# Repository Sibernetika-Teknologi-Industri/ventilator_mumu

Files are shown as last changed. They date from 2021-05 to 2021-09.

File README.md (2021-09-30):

# venti
Low Cost Ventilator - ITB

## Phase 1:
- Kode stepper awal + Kalibrasi
- Kode nextion awal

## Phase 2:
- Kode Integrasi
- Sampai test awal @ salman (8 April 2020)

## Phase 3:
- Pengembangan SIMV

## Phase 4:
- Pengembangan SIMV Lanjutan

## Phase 6:
- Backup setelah uji pre-klinis
- Persiapan pengembangan lanjutan per 25 Mei 2021

## Phase 8:
- IR Calculation from sensor
- Fighting and Spurious Alarm
- Mandatory Pressure Control

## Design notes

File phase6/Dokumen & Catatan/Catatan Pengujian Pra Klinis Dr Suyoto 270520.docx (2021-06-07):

# Catatan Pengujian Pre-klinis Ventilator MUMU

Tanggal: 16 November 2020

Tempat: RS Dr. Suyoto, Jakarta Selatan

Narasumber: Dr.

Notulen: Prasetyo W. (prasetyowls12 at yah00 dot c0m)

Catatan dari Dokter :

1. Tombol EMGS dapat dihapuskan saja (No issues)
2. Alatnya sepertinya lebih baik dijadikan transport (2-3 jam, bisa dicolok ke ambulan, tapi bentuk perlu lebih compact), kalau untuk ICU belum bisa (Diskusi lanjutan di internal→P Augie)
3. Volume kalau bisa hingga 100 cc (untuk anak) (trial & error)-→Harus ada fluke ,diperlukan diskusi di internal→P Augie…(Mempertimbangkan standar yg dipilih antara BPFK dan Masukan Dokter Suyoto)
4. Sensor sirkuit tube udara sebaiknya diletakkan di awal dan di dalam mesin, sehingga tidak keluar banyak selang. -→Isu harus cari komponen Connector Selang (dulu material sulit didapat)
5. Perlu tambahan Indikator RR dan IE aktual pasien (trial & error)
6. Perlu tambahan indicator trigger napas dari pasien. Dari mode mandatory ke assisted tidak perlu dibuat beralih secara otomatis, tetapi ditampilkan indicator trigger saja untuk informasi ke perawat. (trial & error)
7. Perlu ditambahkan mode pressure: mandatory dan assisted (trial & error)---diperlukan narasumber (dokter)-→ utk kepastian agar tidak melakukan kerja ulang.

Punchlist:

1. Perbaikan volume assisted???
2. Perbaikan Fighting / Trigger detection???
3. Perbaikan sensor dan sirkuit udara
4. Penambahan Mode Pressure mandatory dan assited???
5. Penambahan sensor dan indikator aktual IE dan RR
6. Penambahan Volume kalau bisa hingga 100 cc (untuk anak)???
7. Kehandalan sensor volume
8. Koreksi metode instalasi sensor oksigen.
9. Humidifier ?????

Based On Proposal :

1. Detail design Full Scale Sistem Ventilator dengan Sistem Analisis untuk memenuhi Standar ISO 80601-2-12
- Drawing design
2. Satu (1) unit Prototipe Sistem Ventilator dengan Sistem Analisis untuk memenuhi Standar ISO 80601-2-12 yang terdiri dari:
- Analyzer
- ~~Flow Sensor~~
- ~~Humidifier~~
- ~~CO2 Sensor~~
- ~~Exhalation Valve~~
- Gas Mixture System
- ~~Servo Valve~~ ~~(Problem di Oli) –~~ ~~Untuk~~ ~~mixture O2~~
3. Fitur Sistem Ventilator dengan Sistem Analisis untuk memenuhi Standar ISO 80601-2-12
- ~~Volume & rate--~~~~→~~~~Diupdate~~ ~~& explore~~
- ~~Lung Compliance~~
- Safety--→Diupdate & explore
- SIMV (Synchronized Intermittent Mandatory Ventilation)
- ~~O2 Control~~
- ~~PEEP (Positive-end expiratory pressure) Control~~
- ~~Pressure Support~~
- ~~CPAP (Continuous Positive Airways~~ ~~Pressur~~

Kesimpulan :

1. Harus buat produk ventilator dng tambahan fitur
2. Perlu diskusi terkait kepastian desain keseluruhan (default atw explore-→ desain mobile)

Estimasi kalau desain default→3-4 bulan

3. BUat rancangan BOM, Timeline dan Action Plan.

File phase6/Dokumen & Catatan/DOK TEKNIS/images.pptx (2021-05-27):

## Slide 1

Kecepatan
Motor

% Slope Factor
(akselerasi & deselerasi)

Time Exhale

Waktu

Time Inhale

Time Breath

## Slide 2

Tegangan

1 pulse/
1 step

Delay Inhale

Waktu

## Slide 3

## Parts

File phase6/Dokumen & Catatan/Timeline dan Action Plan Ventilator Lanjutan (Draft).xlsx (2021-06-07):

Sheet: Material Order (BoM)
Estimasi BOQ Ventilator (include Fluke)
No | Item | Spesifikasi | Jumlah | Unit | Harga | Total | Referensi
PENGEMBANGAN SISTEM GERAK DAN MOTOR (SISTEM MEKANIK VENTILATOR) |  |  |  |  |  | Rp 50000000.00
1 | Sistem Mekanik & Customize | - Linear Guide - Linear Block - Timing Pulley - Timing Belt - Lengan Penekan - Base - Baki - Motor Holder - Bolt Screw - Nut - Baut,Mur,dll | 1 | set | Rp 25000000.00 | Rp 25000000.00 | Estimasi Biaya Mekanik
2 | Motor Servo | Delta Servo 1,5 kW | 1 | set | Rp 25000000.00 | Rp 25000000.00 | PT Delta
PENGEMBANGAN BREATHING SYSTEM |  |  |  |  |  | Rp 7135000.00
1 | Flow Sensor Hamilton (Tubing) | Support Mesin Ventilator : Type : Adult/Pediatric Galileo/Raphael/C1/T1/MR1/C2/C3 | 1 | pcs | Rp 750000.00 | Rp 750000.00 | https://tokopedia.link/m18e7W5Vjbb
2 | PEEP Valve | PEEP(Positif End Expiratory Pressure) VALVE | 1 | pcs | Rp 1400000.00 | Rp 1400000.00 | https://tokopedia.link/A1IRCEcWjbb
3 | Reusable Resuscitator (Ambu Bag & Accesorries) | - Resuscitator silicon bag x 1pc - Reservoir bag x 1pcs - 02 tubing x 1 pcs '- Mask x 1 pcs - Airway x 3 size 1 pcs each - 1 carry case | 1 | pcs | Rp 750000.00 | Rp 750000.00 | https://tokopedia.link/8MXMOnuWjbb
4 | Breathing Circuit | Breathing Circuit Ventilator Kelengkapan -Circuit -Chamber -Water Trap -Heater wire -Connector | 1 | set | Rp 550000.00 | Rp 550000.00 | https://tokopedia.link/PSInVTSYjbb
5 | Oxygen supply (Tabung) | - Cylinder Tank Ocygen - Furemed Oxygen Regulator - F roda Oxygen CAT - Hospitech Oxygen tubing conn | 1 | set | Rp 1185000.00 | Rp 1185000.00 | Sakura | Perlu ditambahkan aksesoris: 3D printing, dsb
6 | Accessories (3 D Printing, Selang Tambahan) |  | 1 | lot | Rp 2500000.00 | Rp 2500000.00
PENGEMBANGAN SUPPORT DAN CASING |  |  |  |  |  | Rp 7200000.00
1 | Casing | Bahan akrilik | 1 | unit | Rp 1700000.00 | Rp 1700000.00 | PO Cipta Jaya Acrilic
2 | Meja Lemari | Bahan Stainless | 1 | unit | Rp 4500000.00 | Rp 4500000.00 | PO Biru Karya pratama
3 | Accessories (Peredam Suara & Getaran) | Busa , bahan peredam lainnya | 1 | lot | Rp 1000000.00 | Rp 1000000.00
PENGEMBANGAN RANGKAIAN ELEKTRONIK (SISTEM KONTROL VENTILATOR) |  |  |  |  |  | Rp 213923900.00
1 | XL4015 DC-DC Step Down | Variant : Standard | Extra Adjustable Current | Extra Voltmeter Input Voltage : 4 ~ 38 V Adjustable Output Voltage : 1.25 ~ 36 V Output Current : 5A Efficiency : max. 96% Operating Frequency : 180 kHz Operating Temperature : -40° ~ 85° C | 1 | pcs | Rp 25900.00 | Rp 25900.00 | https://tokopedia.link/8o8zMv7Ujbb
2 | Limit Switch CM-1703 | CM Micro Switch Type : CM-1703 Merk : Fort | 2 | pcs | Rp 25000.00 | Rp 50000.00 | https://tokopedia.link/tyngZXiVjbb
3 | Arduino Nano + Kabel | Features: Blue board. Digital I O Pins: 12 (D2 D13) Analog Input Pins: 8 (A0 A7) 1 Pair TTL serial data receiving and transmitting pins: RX TX PWM Output Pins: 6 (D3 D5 D6 D9 D10 D11) Microcontroller: Atmel Atmega328P AU Employs Atmega328P AU single chip Supports USB download and power supply ISP download Supports external 5V 12V DC power supply or 9V battery Comes with cable length: 25cm | 2 | pcs | Rp 50000.00 | Rp 100000.00 | https://tokopedia.link/wg7CSvlWjbb
4 | Raspberry 4 Model B | Broadcom BCM2711, Quad core Cortex-A72 (ARM v8) 64-bit SoC @ 1.5GHz 4GB LPDDR4-3200 SDRAM (depending on model) 2.4 GHz and 5.0 GHz IEEE 802.11ac wireless, Bluetooth 5.0, BLE Gigabit Ethernet 2 USB 3.0 ports; 2 USB 2.0 ports. Raspberry Pi standard 40 pin GPIO header (fully backwards compatible with previous boards) 2 × micro-HDMI ports (up to 4kp60 supported) 2-lane MIPI DSI display port 2-lane MIPI CSI camera port 4-pole stereo audio and composite video port H.265 (4kp60 decode), H264 (1080p60 decode, 1080p30 encode) OpenGL ES 3.0 graphics Micro-SD card slot for loading operating system and data storage | 1 | pcs | Rp 819000.00 | Rp 819000.00 | https://tokopedia.link/Xeqzj8DWjbb
5 | Micro SD | Sandisk MicroSD Ultra UHS-1 A1 64GB Up To 100MB/s Non Adapter | 1 | pcs | Rp 190000.00 | Rp 190000.00 | https://tokopedia.link/fHtZwNSWjbb
6 | LCD Display 7" | 7" Touch Dimension: 194mm x 110mm x 20mm Resolution: 800 x 480 10 points Capacitiv | 1 | pcs | Rp 1125000.00 | Rp 1125000.00 | https://tokopedia.link/IXEFI5YWjbb
7 | ADS 1115 16 bit ADC | Wide Supply Range : 2.0V to 5.5V Low Current Consumption: Continuous Mode : Only 150'A Single-Shot Mode: Auto Shut-Down Programmable Data Rate : 8SPS to 860SPS Internal Low-Drift Voltage reference Internal Oscillator Internal PGA I2C INTERFACE : Pin-Selectable Addresses Four Single-Ended or Two Differential Inputs Programmable Comparator This board/chip uses I2C 7-bit addresses between 0x48-0x4B, selectable with jumpers | 1 | pcs | Rp 31000.00 | Rp 31000.00 | https://tokopedia.link/GMrdyM6Wjbb
8 | Block Terminal AC | - Terminal Block - Terminal block ground rail - Stopper block - Tutup terminal block - Din rail MCB - Fuse Holder - Fuse kaca - Seal silicon ventilator - kontaktor 40A - MCB 20A 2 pull - Jumper terminal block | 1 | set | Rp 3000000.00 | Rp 3000000.00 | Cikapundung
9 | Sensor MPXV7002DP | Features: - -2 to 2 kPa (-0.3 to 0.3 psi). - 0.5 to 4.5 V Output Weight: 0.1 oz; 4 g | 1 | pcs | Rp 450000.00 | Rp 450000.00 | https://tokopedia.link/CzaTtwJXjbb
10 | IC 7404 Inverter | - Terdiri dari 6 unit inverter atau NOT. - Family ACT (advanced CMOS and TTL compatible) memiliki rise time dan fall time yang lebih cepat dari pada family CMOS (CD, HC, HCT) dan TTL (SN, 74xx) biasa - Cocok untuk aplikasi frekuensi tinggi - Vcc : 5 volt - Mampu drive beban 50 ohm - Package: SOIC / SOP 14 pin | 2 | pcs | Rp 12500.00 | Rp 25000.00 | https://tokopedia.link/M2j30QZXjbb
11 | IC Optocoupler | - 16 dip optocoupler CNY74-4 | 2 | pcs | Rp 17500.00 | Rp 35000.00 | https://tokopedia.link/3Gkrd3cYjbb
12 | Kabel Pelangi 50 pin | Tipe: kabel pita pelangi AWG: 28 Jumlah kaki: 50 | 5 | meter | Rp 85000.00 | Rp 425000.00 | https://tokopedia.link/IT0KvSiYjbb
13 | Power Supply 12V 5A | Input Power: 110VAC-220VAC 1PH Output Voltage: 12VDC Rated Current: 5A (Pure) Dimensi: 11cm x 7.7cm x 3.7cm | 1 | pcs | Rp 35000.00 | Rp 35000.00 | https://tokopedia.link/N8grJ5sYjbb
14 | DS3231 RTC module | The 1.-40 ° C to +85 ° C temperature range, timing accuracy kept at ± 5ppm (± 0.432 sec / day) 2 timed to provide continuous battery backup 3 low-power 4. Device package and function compatible with the DS3231 5. Complete clock calendar functions include seconds, minutes, hours, day, date, month and year timing and provide valid until the year 2100 leap year compensation 6 two calendar alarm 7.1Hz and 32.768kHz output 8 Reset button debounced input and output 9-speed (400kHz) I2C serial bus 10. +2.3 V to +5.5 V Supply Voltage 11 ± 3 ° C accuracy digital temperature sensor 12.-40 ° C to +85 ° C operating temperature range 13.16-pin SO (300mil) package 14 by Underwriters Laboratories (UL) certification | 1 | pcs | Rp 20000.00 | Rp 20000.00 | https://tokopedia.link/rUZYjkDYjbb
15 | MPX5700AP (Flow Sensor -->elektronik ) | Model: MPX5700AP Brand: Freescale Freescale Function: MPX5700: 0 to 700kPa, differential, gauge and absolute pressure, integrated pressure sensor Package: in- pressure sensor Condition: 100% brand new original authentic | 1 | pcs | Rp 293000.00 | Rp 293000.00 | https://tokopedia.link/L5T2etKYjbb
16 | KE-25 Oxygen Sensor | * Long life - 2.5~10 years in ambient air * Virtually no influence from CO2, CO, H2S, NOx, H2 * Low cost * Operates in normal ambient temperatures * Stable output signal * No external power supply required for sensor operation * No warmup time is required | 1 | pcs | Rp 2300000.00 | Rp 2300000.00 | https://tokopedia.link/IFoE1exVjbb
17 | Kalibrator | Fluke Gas Analyzer VT650 | 1 | unit | Rp 180000000.00 | Rp 180000000.00 | Estimasi (Jika beli baru)
18 | Accessories | - Resistor - PCB - Tombol ON/OFF - Emergency Button - Konektor Selang - Selang bening - White Housing Male/Female - Solder - Timah Solder - Foam Double Tape - Kipas Pendingin - Kabel Jumper Tunggal - Casing Raspberry - Socket IC - Transistor Switch - Male/Female Pin Header | 1 | set | Rp 25000000.00 | Rp 25000000.00 | Estimasi Biaya Aksesoris
PENGEMBANGAN BACKUP POWER |  |  |  |  |  | Rp 20000000.00
1 | UPS 3000V (Included Batere) | APC | 1 | set | Rp 20000000.00 | Rp 20000000.00 | Estimasi
ESTIMASI TOTAL MATERIAL VENTILATOR |  |  |  |  |  | Rp 298258900.00
Notes : (Additional Berdasarkan Proposal)
1 | Humidifier | Mekanik (Breathing System) | 1 | set | Rp 2000000.00 | Rp 2000000.00 | Estimasi
2 | CO2 | Sensor (System Kontrol ) | 1 | set | Rp 3000000.00 | Rp 3000000.00 | Estimasi
3 | Exhalation Valve |  | 1 | set | Rp 2000000.00 | Rp 2000000.00 | Estimasi
4 | Servo Valve | Valve (System Kontrol ) | 1 | set | Rp 2000000.00 | Rp 2000000.00 | Estimasi
 |  |  |  |  |  | Rp 9000000.00

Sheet: Timeline Riset Ventilator
TIMELINE
VENTILATOR RESEARCH
No | Description | Personil | Duration |  | M1 |  |  |  | M2 |  |  |  |  | M3 |  |  |  | M4 |  |  |  | M5 |  |  |  |  | M6 |  |  |  | M7 |  |  |  | M8 |  |  |  | M9
 |  |  |  |  | W1 | W2 | W3 | W4 | W5 | W6 | W7 | W8 | W9 | W10 | W11 | W12 | W13 | W14 | W15 | W16 | W17 | W18 | W19 | W20 | W21 | W22 | W23 | W24 | W25 | W26 | W23 | W24 | W25 | W26 | W23 | W24 | W25 | W26 | W23 | W24 | W25 | W26
 |  |  |  |  | 31-6 | 7-13 | 14-20 | 21-27 | 28-4 | 5-11 | 12-18 | 19-25 | 26-1 | 1-7 | 8-14 | 15-21 | 22-28 | 29-5 | 6-12 | 13-19 | 20-26 | 27-3 | 4-10 | 11-17 | 18-24 | 25-31 | 1-7 | 8-14 | 15-21 | 22-30 | 1-7 | 8-14 | 15-21 | 22-30 | 1-7 | 8-14 | 15-21 | 22-30 | 1-7 | 8-14 | 15-21 | 22-30
PERANCANGAN DESAIN & DEVELOPMENT VENTILATOR
A | PENGEMBANGAN SISTEM GERAK DAN MOTOR (SISTEM MEKANIK VENTILATOR) | PENELITI, QC/QA, SYS E, SE, ELEC E | 12 | weeks
 | 1. Rancangan Desain Rangka & Mesin Ventilator |  | 4 | weeks
 | 2. Penyusunan sistem gerak dan motor
 | Pengadaan peralatan sistem motor |  | 8 | weeks
 | Pengadaan peralatan aksesoris breathing system |  | 8 | weeks
 | 3. Pembuatan / manufakturing kerangka mekanik |  | 4 | weeks
 | 4. Pembuatan support dan casing
 | Pengadaan peralatan casing |  | 4 | weeks
B | PENGEMBANGAN SISTEM KONTROL VENTILATOR | PENELITI, QC/QA, SYS E, SE, ELEC E | 18 | weeks
 | 1. Pengembangan rangkaian elektronik
 | Pengadaan rangkaian elektronik |  | 8 | weeks
 | Survey terkait servo valve tanpa pelumas (medical grade) |  | 8 | weeks
 | Cetak dan merangkai rangkaian elektronik |  | 3 | weeks
 | 2. Pemprograman kontrol Ventilator
 | 1. Pengembangan program deteksi sensor
 | Test dan Kalibrasi sensor Pressure |  | 3 | weeks
 | Test dan Kalibrasi sensor Flow |  | 3 | weeks
 | Test dan Kalibrasi sensor O2 |  | 3 | weeks
 | Test dan Kalibrasi sensor CO2 |  | 3 | weeks
 | Test dan kalibrasi algoritma integral Volume |  | 3 | weeks
 | Test dan Kalibrasi algoritma IPP, PIP, PEEP |  | 3 | weeks
 | Test dan Kalibrasi algoritma IE dan RR |  | 2 | weeks
 | Test dan Kalibrasi algoritma trigger napas |  | 2 | weeks
 | Test dan Kalibrasi algoritma Lung Compliance |  | 2 | weeks
 | Test dan Kalibrasi algoritma kontrol O2 mixture valve |  | 2 | weeks
 | Test dan Kalibrasi algoritma kontrol dan display PEEP |  | 2 | weeks
 | Test dan Kalibrasi Humidifier |  | 2 | weeks
 | 2. Pengembangan program alarm
 | Alarm 1: Trigger Napas |  | 2 | weeks
 | Alarm 2: Over Pressure |  | 2 | weeks
 | Alarm 3: Low PEEP |  | 2 | weeks
 | Alarm 4: O2 Tolerance |  | 2 | weeks
 | Utilitas Alarm (Prioritas, Reset, Mute) |  | 2 | weeks
 | 3. Pengembangan program aktuator motor
 | Pengujian & kalibrasi awal motor servo |  | 2 | weeks
 | Mandatory Volume |  | 2 | weeks
 | Assisted / Trigger Volume |  | 3 | weeks
 | Mandatory Pressure |  | 3 | weeks
 | Assisted / Trigger Pressure |  | 3 | weeks
 | Algoritma Safety (integrasi dengan program alarm) |  | 2 | weeks
 | 4. Pengembangan program dashboard |  | 4 | weeks
 | 5. Pengembangan program data |  | 4 | weeks
C | PENGEMBANGAN SISTEM POWER SUPPLY (BACKUP BATTERY) | QC/QA, SYS E, ELEC E | 2 | weeks
 | Pengadaan peralatan UPS (Termasuk Battery) |  | 2 | weeks
D | INTEGRASI SYSTEM | QC/QA, SE, SYS E | 12 | weeks
 | 1. Integrasi sistem mekanik dengan sistem power supply |  | 12 | weeks
 | 2. Integrasi sistem kontrol dengan sistem mekanik ventilator |  | 12 | weeks
PENGETESAN PROTOTYPE (INTERNAL TEST) |  |  | 8 | weeks
E | 1. Functional Test & Fixing Problems (Mekanik Fungsional) | PENELITI, QC/QA, SE, SYS E, TECH W | 4 | weeks
 | 2. Functional Test & Fixing Problems (Desain & System Fungsional) | PENELITI, QC/QA, SE, SYS E, TECH W | 4 | weeks
PENGETESAN FINAL PRODUK (BPFK atw Lainnya) |  |  | 4 | weeks
F | Performance Test & Repair (All system) | PM, QC/QA, PENELITI, SE, SYS E | 4 | weeks
PELAPORAN FINAL |  |  | 16 | weeks
G | Pembuatan Laporan Final & Drawing | QC/QA, PENELITI, SYS E, TECH W | 16 | weeks

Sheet: Action Plan
ACTION PLAN
DEVELOPMENT VENTILATOR
No. | Action Plan |  |  |  |  |  |  |  |  | PIC | TARGET | STATUS
PERANCANGAN DESAIN & DEVELOPMENT VENTILATOR
1 | Rancangan Desain Rangka Mekanik Ventilator |  |  |  |  |  |  |  |  | SAM | 4 Weeks | NEXT ACTION
2 | Melakukan Procurement (ORDER # 1) :--->MOS |  |  |  |  |  |  |  |  | AAZ, SAM, HAM |  | NEXT ACTION
 | PENGEMBANGAN SISTEM GERAK DAN MOTOR (SISTEM MEKANIK VENTILATOR) |  |  |  |  |  |  |  |  |  | 8 Weeks
 | PENGEMBANGAN BREATHING SYSTEM |  |  |  |  |  |  |  |  |  | 8 Weeks
 | PENGEMBANGAN RANGKAIAN ELEKTRONIK (SISTEM KONTROL VENTILATOR)
 | Survey terkait servo valve tanpa pelumas (medical grade) |  |  |  |  |  |  |  |  |  | 4 Weeks
 | Cetak dan merangkai rangkaian elektronik |  |  |  |  |  |  |  |  |  | 4 Weeks
3 | Melakukan Procurement (ORDER # 2) :---->MOS |  |  |  |  |  |  |  |  | AAZ, SAM, HAM |  | NEXT ACTION
 | PENGEMBANGAN SUPPORT DAN CASING |  |  |  |  |  |  |  |  |  | 4 Weeks
 | PENGEMBANGAN BACKUP POWER |  |  |  |  |  |  |  |  |  | 4 Weeks
 | Accessories for Ventilator Installation |  |  |  |  |  |  |  |  |  | 4 Weeks
4 | Pembuatan / manufakturing kerangka mekanik |  |  |  |  |  |  |  |  | SAM | 4 Weeks | NEXT ACTION
5 | Melakukan Development Research (Assembly, Programming & Functional Test) :
 | 1. Melakukan Pengembangan Sistem Kontrol (Pemprograman kontrol Ventilator) | 2. Assembly Stage 2 ( High Level) | 2. Assembly Stage 2 ( High Level) | 2. Assembly Stage 2 ( High Level) | 2. Assembly Stage 2 ( High Level) | 2. Assembly Stage 2 ( High Level) | 2. Assembly Stage 2 ( High Level) | 2. Assembly Stage 2 ( High Level) | 2. Assembly Stage 2 ( High Level)
 | 1. Pengembangan program deteksi sensor |  |  |  |  |  |  |  |  | HAM |  | NEXT ACTION
 | Test dan Kalibrasi sensor Pressure |  |  |  |  |  |  |  |  |  | 3 weeks
 | Test dan Kalibrasi sensor Flow |  |  |  |  |  |  |  |  |  | 3 weeks
 | Test dan Kalibrasi sensor O2 |  |  |  |  |  |  |  |  |  | 3 weeks
 | Test dan Kalibrasi sensor CO2 |  |  |  |  |  |  |  |  |  | 3 weeks
 | Test dan kalibrasi algoritma integral Volume |  |  |  |  |  |  |  |  |  | 3 weeks
 | Test dan Kalibrasi algoritma IPP, PIP, PEEP |  |  |  |  |  |  |  |  |  | 3 weeks
 | Test dan Kalibrasi algoritma IE dan RR |  |  |  |  |  |  |  |  |  | 2 weeks
 | Test dan Kalibrasi algoritma trigger napas |  |  |  |  |  |  |  |  |  | 2 weeks
 | Test dan Kalibrasi algoritma Lung Compliance |  |  |  |  |  |  |  |  |  | 2 weeks
 | Test dan Kalibrasi algoritma kontrol O2 mixture valve |  |  |  |  |  |  |  |  |  | 2 weeks
 | Test dan Kalibrasi algoritma kontrol dan display PEEP |  |  |  |  |  |  |  |  |  | 2 weeks
 | Test dan Kalibrasi Humidifier |  |  |  |  |  |  |  |  |  | 2 weeks
 | 2. Pengembangan program alarm |  |  |  |  |  |  |  |  | HAM |  | NEXT ACTION
 | Alarm 1: Trigger Napas |  |  |  |  |  |  |  |  |  | 2 weeks
 | Alarm 2: Over Pressure |  |  |  |  |  |  |  |  |  | 2 weeks
 | Alarm 3: Low PEEP |  |  |  |  |  |  |  |  |  | 2 weeks
 | Alarm 4: O2 Tolerance |  |  |  |  |  |  |  |  |  | 2 weeks
 | Utilitas Alarm (Prioritas, Reset, Mute) |  |  |  |  |  |  |  |  |  | 2 weeks
 | 3. Pengembangan program aktuator motor |  |  |  |  |  |  |  |  | HAM |  | NEXT ACTION
 | Pengujian & kalibrasi awal motor servo |  |  |  |  |  |  |  |  |  | 2 weeks
 | Mandatory Volume |  |  |  |  |  |  |  |  |  | 2 weeks
 | Assisted / Trigger Volume |  |  |  |  |  |  |  |  |  | 3 weeks
 | Mandatory Pressure |  |  |  |  |  |  |  |  |  | 3 weeks
 | Assisted / Trigger Pressure |  |  |  |  |  |  |  |  |  | 3 weeks
 | Algoritma Safety (integrasi dengan program alarm) |  |  |  |  |  |  |  |  |  | 2 weeks
 | 4. Pengembangan program dashboard |  |  |  |  |  |  |  |  | HAM | 4 Weeks | NEXT ACTION
 | 5. Pengembangan program data |  |  |  |  |  |  |  |  | HAM | 4 Weeks | NEXT ACTION
6 | Melakukan Integrasi System : |  |  |  |  |  |  |  |  | SAM, HAM |  | NEXT ACTION
 | 1. Integrasi sistem mekanik dengan sistem power supply |  |  |  |  |  |  |  |  |  | 12 Weeks
 | 2. Integrasi sistem kontrol dengan sistem mekanik ventilator |  |  |  |  |  |  |  |  |  | 12 Weeks
PENGETESAN PROTOTYPE (INTERNAL TEST)
7 | Melakukan Fuctional Test & Fixing Problems |  |  |  |  |  |  |  |  | SAM, HAM |  | NEXT ACTION
 | 1. Functional Test & Fixing Problems (Mekanik Fungsional) |  |  |  |  |  |  |  |  |  | 4 Weeks
 | 2. Functional Test & Fixing Problems (Desain & System Fungsional) |  |  |  |  |  |  |  |  |  | 4 Weeks
PENGETESAN FINAL PRODUK (BPFK atw Lainnya)
8 | Performance Test & Repair (All system)--->BPFK atw lainnya |  |  |  |  |  |  |  |  | SAM, HAM | 4 Weeks | NEXT ACTION
9 | Pembuatan Laporan Final & Drawing |  |  |  |  |  |  |  |  | HAM | 16 Weeks | NEXT ACTION

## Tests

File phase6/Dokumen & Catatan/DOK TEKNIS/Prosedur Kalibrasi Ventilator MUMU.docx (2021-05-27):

# Prosedur Kalibrasi Ventilator MUMU

Oleh: Prasetyo W. (prasetyowls12@yahoo.com)

## 1. Penjelasan Tabel Isian (file format_kalibrasi.xlxs)

Periksa ilustrasi pergerakan motor pada akhir bagian ini.

A. Kolom ‘Input’

Berisi kombinasi nilai set point yang ingin dikalibrasi, yaitu: 1) Volume (Vol); 2) Inhale to Exhale Ratio (IE); 3) Respiratory Rate (RR).

Volume adalah volume tidal yang ingin dicapai. IE adalah perbandingan waktu inhale dan exhale (misal isian 2 menunjukkan rasio waktu untuk Inhale:Exhale = 1:2). RR adalah jumlah siklus pernapasan dalam satu menit.

Misal apabila input: volume 300 cc, IE 1:2, RR 20. Maka dalam satu menit akan dilakukan 12 kali pernapasan, atau satu siklus napas akan memakan waktu 60/12 = 3 detik. Inhale akan memakan waktu 1 detik dan exhale akan memakan waktu 2 detik.

B. Kolom ‘Settings’

Berisi nilai yang diubah-ubah untuk mencapai nilai set-point pada kolom input, yaitu: 1) Jumlah step inhale (step); 2) Waktu delay Inhale (dTi).

Step adalah jumlah step yang perlu dilakukan oleh servo untuk dapat mencapai volume set-point. Satu step dikirimkan sebagai satu sinyal pulse (naik-turun dengan duty cycle 50%) dengan periode tertentu (atau bisa disebut juga delay per pulse naik atau per pulse turun berapa).

Waktu delay inhale adalah jumlah waktu yang ditambahkan ke ‘time inhale’ untuk mengkompensasi dinamika ambu bag. Perintah yang dikirimkan ke motor servo berupa step yang harus dilakukan motor dalam jangka waktu tertentu. Karena adanya dinamika pada ambu (resistansi, slip, dsb) maka terkadang IE yang didapat tidak terlalu tepat. Waktu delay inhale membantu untuk tuning IE, karena akan mengubah waktu delay per pulse naik/turun sehingga mempercepat/memperlambat gerakan motor.

Step → Tuning Volume

dTi → Tuning IE

C. Kolom ‘Measurements’

Berisi nilai yang terbaca dari alat pengukuran (FLUKE), yaitu: 1) I:E; dan 2) Volume Tidal. Dua nilai ini nantinya dipakai sebagai parameter performansi ventilator.

D. Kolom ‘Calculation’

Berisi perhitungan nilai-nilai yang diperlukan untuk mengukur performa ventilator, yaitu:

1) Waktu total pernapasan (Time Breath) - Ideal;

2) Waktu total untuk inhale (Time Inhale) - Aktual;

3) Waktu total untuk exhale (Time Exhale) – Aktual;

4) Selisih waktu inhale dan exhale aktual, apabila diskalakan pada rasio IE ideal (delta Ti)

Misal: IE measurement 1:1.98 pada RR 12, IE Ideal 1:2

Time Breath = 5 detik; Time Inhale = 1.678 detik; Time exhale = 3.322 detik

Delta Ti = 3.322 – 1.678 * 2 = -0.034 detik

Dari sini dapat diketahui bahwa setting dTi perlu dikurangi (agar inhale lebih sebentar)

5) Selisih volume aktual dan set point (delta volume)

E. Kolom ‘Results’

Berisi hasil-hasil tambahan untuk mengukur performa ventilator, yaitu:

1) Estimasi Rpm Motor
2) Estimasi Pulse per Second Motor (dihitung dari 1 detik per periode 1 pulsa)
3) % kesalahan volume
4) % kesalahan IE

Diusahakan % kesalahan masuk dalam rentang 10 persen

F. Kolom Warning

Kolom warning terletak pada kolom A spreadsheet. Kolom ini diisi dengan ‘v’ apabila tidak ditemukan kombinasi step dan dTi yang bisa memenuhi input karena tekanan berlebih (sehingga katup safety terbuka dan udara terbuang).

Apabila terdapat kasus seperti ini, kalibrasi dilakukan dengan mengunci safety valve, kemudian memasukkan nilai setting yang dapat mencapai set point input dalam kondisi ini.

Meski begitu, pada kolom measurement dituliskan hasil bacaan FLUKE dalam kondisi safety valve tidak terkunci.

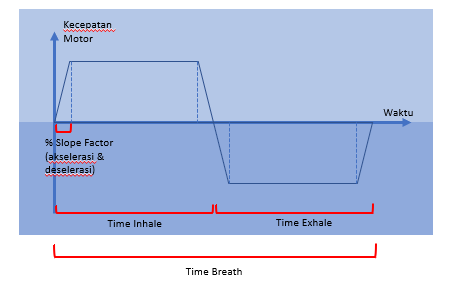
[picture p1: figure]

Gambar 1. Ilustrasi Siklus Pernapasan

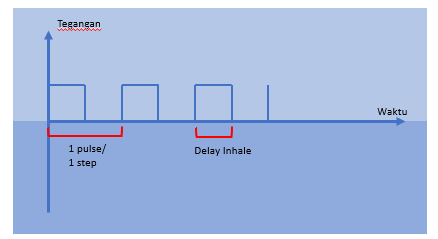
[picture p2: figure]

Gambar 2. Ilustrasi pulsa penggerak motor servo

## 2. Prosedur Kalibrasi Ventilator MUMU

1. Akses raspberry pi ventilator melalui VNCviewer
2. Buka terminal kemudian nonaktifkan node red dengan node-red-stop
3. Pastikan emergency button tidak aktif
4. Buka Arduino IDE dan setting port sesuai Arduino Motor, kemudian buka Serial Monitor (Baud 115200)
5. Ketikkan perintah dalam format sebagai berikut:

< a, b, c, d, e>

dengan nilai masing-masing:

a) Mode: 1 aktif, 0 non aktif
b) Step: jumlah step inhale yang akan dijalankan
c) RR: Respiratory Rate
d) IE: Inhale:Exhale ratio
e) dTi: delay time inhale

Sesuaikan hingga tercapai vol dan IE yang sesuai (step untuk mencapai vol, dTi untuk mencapai IE). Ketikkan nilai setting dan measurement pada kolom yang sesuai.

6. Setelah selesai, aktifkan Kembali node-red dengan mengetikkan node-red-start pada terminal

## 3. Prosedur Upload Data Via Terminal Ke MySQL

1. Export data pada sheet ‘MySQL’ di file format_kalibrasi.xlxs ke dalam bentuk csv, lalu hapus baris pertama (header)
2. Transfer data csv tersebut ke folder ~/ventilator/kalibrasi/ pada raspberry
3. Pada terminal raspberry pi, masuk ke MySql dengan ‘sudo mysql -u ventinesia -p’. Kemudian ketikkan password ‘ventilator’
4. Jalankan perintah-perintah berikut

// untuk mengaktifkan database ventilator

USE ventilator;

// untuk melihat daftar tabel dan melihat isi tabel

SHOW TABLES;

SELECT * FROM kalibrasi2;

// untuk membuat tabel baru

CREATE TABLE `kalibrasi3` (

`no` INT NOT NULL AUTO_INCREMENT ,

`warn` INT NOT NULL ,

`erat` INT NOT NULL ,

`vti` INT NOT NULL ,

`rr` INT NOT NULL ,

`dti` FLOAT NOT NULL ,

`step` INT NOT NULL ,

PRIMARY KEY (`no`)

);

// untuk mengisi tabel baru dengan file csv

load data local infile '/home/pi/ventilator/kalibrasi/Kalibrasi5Aug.csv'

into table kalibrasi3

fields terminated by ','

enclosed by '"'

lines terminated by '\n'

(warn, erat, vti, rr, dti, step);

// untuk menghapus tabel

DROP TABLE kalibrasi3;

5. Pada node-red raspberry, bagian ‘Aktuator Motor’ ubah nama tabel pada node function sebelum node database (pada pernyataan msg.topic)

## 4. Catatan Tambahan (Per 27 Mei 2021)

Ventilator MUMU PT Sibernetika

Login:

user: pi

pass: ventilator

NodeRed (port 1880)

user: admin

pass: ventilator

MySQL (port 3306, sudo mysql -u ventinesia -p)

user: ventinesia

pass: ventilator

database: ventilator

table: kalibrasi2

install awal: https://pimylifeup.com/raspberry-pi-mysql/

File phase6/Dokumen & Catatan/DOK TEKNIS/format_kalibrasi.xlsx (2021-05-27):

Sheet: Format
Warning | Input |  |  | Settings |  | Measurements |  | Calculation |  |  |  |  | Results
 | IE | Vti | RR | dTi | Step | IE | Tidal Volume | Time Breath | Time Inhale | Time Exhale | Delta Ti | Delta Volume | Rpm (est) | PPS (est) | dVol (%) | dIE(%)
 | 1 | 300 | 10 |  |  |  |  | 6.00 | 6.00 | 0.00 | -6.00 | -300 | #DIV/0! | #DIV/0! | -100.0 | -100.00
 | 1 | 300 | 12 |  |  |  |  | 5.00 | 5.00 | 0.00 | -5.00 | -300 | #DIV/0! | #DIV/0! | -100.0 | -100.00
 | 1 | 300 | 14 |  |  |  |  | 4.29 | 4.29 | 0.00 | -4.29 | -300 | #DIV/0! | #DIV/0! | -100.0 | -100.00
 | 1 | 300 | 15 |  |  |  |  | 4.00 | 4.00 | 0.00 | -4.00 | -300 | #DIV/0! | #DIV/0! | -100.0 | -100.00
 | 1 | 300 | 16 |  |  |  |  | 3.75 | 3.75 | 0.00 | -3.75 | -300 | #DIV/0! | #DIV/0! | -100.0 | -100.00
 | 1 | 300 | 18 |  |  |  |  | 3.33 | 3.33 | 0.00 | -3.33 | -300 | #DIV/0! | #DIV/0! | -100.0 | -100.00
 | 1 | 300 | 20 |  |  |  |  | 3.00 | 3.00 | 0.00 | -3.00 | -300 | #DIV/0! | #DIV/0! | -100.0 | -100.00
 | 1 | 300 | 25 |  |  |  |  | 2.40 | 2.40 | 0.00 | -2.40 | -300 | #DIV/0! | #DIV/0! | -100.0 | -100.00
 | 1 | 300 | 30 |  |  |  |  | 2.00 | 2.00 | 0.00 | -2.00 | -300 | #DIV/0! | #DIV/0! | -100.0 | -100.00
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

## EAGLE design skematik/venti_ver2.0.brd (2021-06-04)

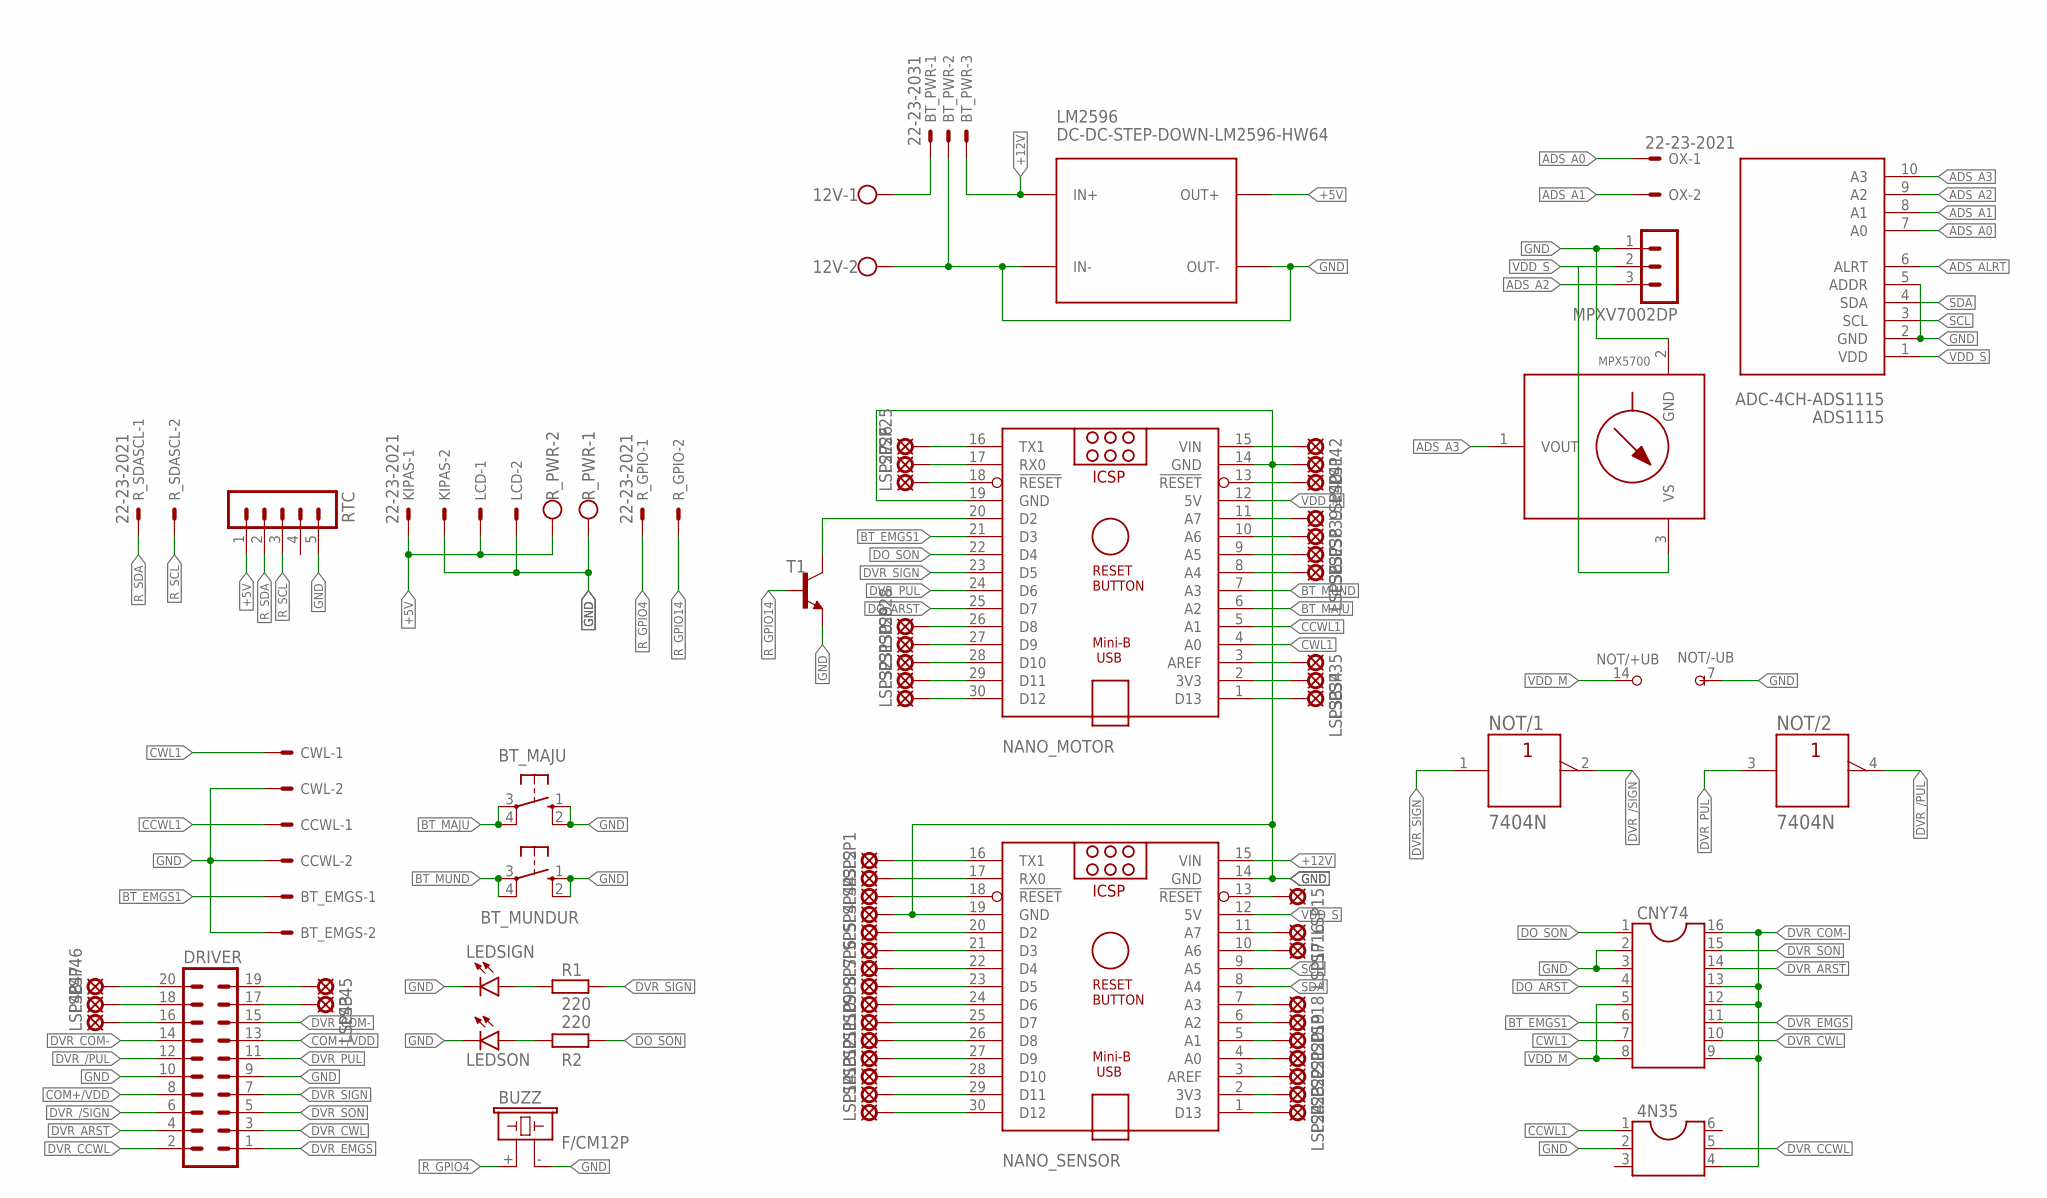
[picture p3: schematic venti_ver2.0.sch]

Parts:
4N35: DIL6; DIL06
12V: W237-102
ADS1115: ADC-4CH-ADS1115
BT_EMGS: 22-23-2021
BT_MAJU: 40-XX; B3F-40XX
BT_MUNDUR: 40-XX; B3F-40XX
BT_PWR: 22-23-2031
BUZZ: F/CM12P
CCWL: 22-23-2021
CNY74: DIL16
CWL: 22-23-2021
DRIVER: ML20
KIPAS: 22-23-2021
LCD: 22-23-2021
LEDSIGN: LED5MM
LEDSON: LED5MM
LM2596: DC-DC-STEP-DOWN-LM2596-HW64; DC-DC-STEP-DOWN-LM2596
LSP1, LSP2, LSP3, LSP4, LSP5, LSP6, LSP7, LSP8, LSP9, LSP10, LSP11, LSP12, LSP13, LSP14, LSP15, LSP16, LSP17, LSP18, LSP19, LSP20, LSP21, LSP22, LSP23, LSP24, LSP25, LSP26, LSP27, LSP28, LSP29, LSP30, LSP31, LSP32, LSP33, LSP34, LSP35, LSP36, LSP37, LSP38, LSP39, LSP40, LSP41, LSP42, LSP43, LSP44, LSP45, LSP46, LSP47, LSP48: LSP11
MPX5700: MPX-867B-H; 867B-H
MPXV7002DP: MA03-1
NANO_MOTOR: ARDUINO_NANO
NANO_SENSOR: ARDUINO_NANO
NOT: 7404N; DIL14
OX: 22-23-2021
R1, R2: 220; 0204/7
RTC: MA05-1
R_GPIO: 22-23-2021
R_PWR: W237-102
R_SDASCL: 22-23-2021
T1: 2N2222-NPN-TO92-EBC; TO92-EBC

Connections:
+5V: KIPAS.1, LCD.1, LM2596.OUT+, RTC.1, R_PWR.2
+12V: BT_PWR.3, LM2596.IN+, NANO_SENSOR.15 (VIN)
ADS_A0: ADS1115.7 (A0), OX.1
ADS_A1: ADS1115.8 (A1), OX.2
ADS_A2: ADS1115.9 (A2), MPXV7002DP.3
ADS_A3: ADS1115.10 (A3), MPX5700.1 (VOUT)
ADS_ALRT: ADS1115.6 (ALRT)
BT_EMGS1: BT_EMGS.1, CNY74.6, NANO_MOTOR.21 (D3)
BT_MAJU: BT_MAJU.3, BT_MAJU.4 (P1), NANO_MOTOR.6 (A2)
BT_MUND: BT_MUNDUR.3, BT_MUNDUR.4 (P1), NANO_MOTOR.7 (A3)
CCWL1: 4N35.1, CCWL.1, NANO_MOTOR.5 (A1)
COM+/VDD: DRIVER.8, DRIVER.13
CWL1: CNY74.7, CWL.1, NANO_MOTOR.4 (A0)
DO_ARST: CNY74.4, NANO_MOTOR.25 (D7)
DO_SON: CNY74.1, NANO_MOTOR.22 (D4), R2.2
DVR_/PUL: DRIVER.12, NOT.4 (Y)
DVR_/SIGN: DRIVER.6, NOT.2 (Y)
DVR_ARST: CNY74.14, DRIVER.4
DVR_CCWL: 4N35.5, DRIVER.2
DVR_COM-: 4N35.4, CNY74.9, CNY74.12, CNY74.13, CNY74.16, DRIVER.14, DRIVER.15
DVR_CWL: CNY74.10, DRIVER.3
DVR_EMGS: CNY74.11, DRIVER.1
DVR_PUL: DRIVER.11, NANO_MOTOR.24 (D6), NOT.3 (A)
DVR_SIGN: DRIVER.7, NANO_MOTOR.23 (D5), NOT.1 (A), R1.2
DVR_SON: CNY74.15, DRIVER.5
GND: 4N35.2, 12V.2, ADS1115.2 (GND), ADS1115.5 (ADDR), BT_EMGS.2, BT_MAJU.1 (S), BT_MAJU.2 (S1), BT_MUNDUR.1 (S), BT_MUNDUR.2 (S1), BT_PWR.2, BUZZ.- (2), CCWL.2, CNY74.2, CNY74.3, CWL.2, DRIVER.9, DRIVER.10, KIPAS.2, LCD.2, LEDSIGN.K (C), LEDSON.K (C), LM2596.IN-, LM2596.OUT-, LSP41.MP, LSP44.MP, MPX5700.2 (GND), MPXV7002DP.1, NANO_MOTOR.14 (GND), NANO_MOTOR.19 (GND), NANO_SENSOR.14 (GND), NANO_SENSOR.19 (GND), NOT.7 (-UB), RTC.5, R_PWR.1, T1.E
unnamed: NANO_MOTOR.20 (D2), T1.C
unnamed: LEDSIGN.A, R1.1
unnamed: LEDSON.A, R2.1
unnamed: 12V.1, BT_PWR.1
unnamed: LSP1.MP, NANO_SENSOR.16 (TX1)
unnamed: LSP2.MP, NANO_SENSOR.17 (RX0)
unnamed: LSP3.MP, NANO_SENSOR.18 (!RESET)
unnamed: LSP4.MP, NANO_SENSOR.20 (D2)
unnamed: LSP5.MP, NANO_SENSOR.21 (D3)
unnamed: LSP6.MP, NANO_SENSOR.22 (D4)
unnamed: LSP7.MP, NANO_SENSOR.23 (D5)
unnamed: LSP8.MP, NANO_SENSOR.24 (D6)
unnamed: LSP9.MP, NANO_SENSOR.25 (D7)
unnamed: LSP10.MP, NANO_SENSOR.26 (D8)
unnamed: LSP11.MP, NANO_SENSOR.27 (D9)
unnamed: LSP12.MP, NANO_SENSOR.28 (D10)
unnamed: LSP13.MP, NANO_SENSOR.29 (D11)
unnamed: LSP14.MP, NANO_SENSOR.30 (D12)
unnamed: LSP15.MP, NANO_SENSOR.13 (!RESET)
unnamed: LSP16.MP, NANO_SENSOR.11 (A7)
unnamed: LSP17.MP, NANO_SENSOR.10 (A6)
unnamed: LSP18.MP, NANO_SENSOR.7 (A3)
unnamed: LSP19.MP, NANO_SENSOR.6 (A2)
unnamed: LSP20.MP, NANO_SENSOR.5 (A1)
unnamed: LSP21.MP, NANO_SENSOR.4 (A0)
unnamed: LSP22.MP, NANO_SENSOR.3 (AREF)
unnamed: LSP23.MP, NANO_SENSOR.2 (3V3)
unnamed: LSP24.MP, NANO_SENSOR.1 (D13)
unnamed: LSP25.MP, NANO_MOTOR.16 (TX1)
unnamed: LSP26.MP, NANO_MOTOR.17 (RX0)
unnamed: LSP27.MP, NANO_MOTOR.18 (!RESET)
unnamed: LSP28.MP, NANO_MOTOR.26 (D8)
unnamed: LSP29.MP, NANO_MOTOR.27 (D9)
unnamed: LSP30.MP, NANO_MOTOR.28 (D10)
unnamed: LSP31.MP, NANO_MOTOR.29 (D11)
unnamed: LSP32.MP, NANO_MOTOR.30 (D12)
unnamed: LSP33.MP, NANO_MOTOR.1 (D13)
unnamed: LSP34.MP, NANO_MOTOR.2 (3V3)
unnamed: LSP35.MP, NANO_MOTOR.3 (AREF)
unnamed: LSP36.MP, NANO_MOTOR.8 (A4)
unnamed: LSP37.MP, NANO_MOTOR.9 (A5)
unnamed: LSP38.MP, NANO_MOTOR.10 (A6)
unnamed: LSP39.MP, NANO_MOTOR.11 (A7)
unnamed: LSP40.MP, NANO_MOTOR.13 (!RESET)
unnamed: LSP42.MP, NANO_MOTOR.15 (VIN)
unnamed: DRIVER.17, LSP43.MP
unnamed: DRIVER.19, LSP45.MP
unnamed: DRIVER.16, LSP48.MP
unnamed: DRIVER.18, LSP47.MP
unnamed: DRIVER.20, LSP46.MP
R_GPIO4: BUZZ.+ (1), R_GPIO.1
R_GPIO14: R_GPIO.2, T1.B
R_SCL: RTC.3, R_SDASCL.2
R_SDA: RTC.2, R_SDASCL.1
SCL: ADS1115.3 (SCL), NANO_SENSOR.9 (A5)
SDA: ADS1115.4 (SDA), NANO_SENSOR.8 (A4)
VDD_M: CNY74.5, CNY74.8, NANO_MOTOR.12 (5V), NOT.14 (+UB)
VDD_S: ADS1115.1 (VDD), MPX5700.3 (VS), MPXV7002DP.2, NANO_SENSOR.12 (5V)

Board: 2 copper layers, 78 parts (3 on the bottom side), 83 nets, no tracks yet.

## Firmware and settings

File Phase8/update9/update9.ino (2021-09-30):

/*
********************************************************
* Kode Untuk menggerakkan servo
* Bagian dari project Ventilator MUMU
* PT Sibernetika Teknologi Industri
*
* Device: Arduino Nano
* Author:
*      - Prasetyo Wibowo LS. (prasetyowls12 (at) yahoo (dot) com)
*********************************************************
*/

/* KONFIGURASI PIN *****************************
* ENA     (DO)    PIN ENABLE
* PUL     (DO)    PIN PULSE
* DIR     (DO)    PIN ARAH
* ARST    (DO)    PIN RESET
* CWL     (DI)    LIMIT SWITCH CLOCKWISE
* CCWL    (DI)    LIMIT SWITCH COUNTER-CLOCKWISE
* EMGS    (DI)    EMERGENCY BUTTON
* WARNN   (DI)    WARN TRIGGER (INTERRUPT)
* Bt1     (DI)    TOMBOL UNTUK MENGGERAKAN MANUAL (MAJU)
* Bt2     (DI)    TOMBOL UNTUK MENGGERAKAN MANUAL (MUNDUR)
*************************************************/
#define ENA 8
#define PUL 10
#define DIR 9
#define ARST 7
#define CWL 4
#define CCWL 5
#define EMGS 3
#define WARNN 2
#define Bt1 A4
#define Bt2 A5

/* DEFINISI VARIABEL ****************************
*  slopeFactor  =   Faktor Sloping untuk akselerasi
*  Offsetq      =   Offset untuk
*  dirInhale    =   Tegangan yang membuat motor gerak ke arah inhale (HIGH)
*  delayq       =   Delay pulse untuk gerakan santai (input manual dari button)
*  IRat         =   Ratio Inhale
*************************************************/
#define slopeFactor 0.35
#define offsetq 11
#define dirInhale HIGH
#define delayq 2000
#define IRat 1

/* GLOBAL VARIABLEs ******************************/
unsigned long stepTidal, delayInhale, delayExhale;
float timeInhale, timeExhale, timeBreath;
float initDelay = 25;

unsigned long p_vol, p_RR, p_pres;
float p_IE, p_press;
int p_mode = 0;
float p_del = 0;
bool warnq = false;

int num_buf = 7;
String bufferq[7];
String lastData = "<0,0,0,0,0,0,0>";
bool updated = false;

unsigned long stepstop = 0;
int stepq = 0;
int presok = 0;
int presok2 = 0;
int presok3 = 0;


/* FUNCTION PROMISES ****************************/
// Comm Functions
void updateAllGlobal();
String readSerial();
void updateParam(float, int, float);

// Movement Functions
int Inhale2();
void Exhale(int);

int Inhale3();
void Exhale3(int);

// Interrupt Functions
void updateEMGS();
void triggerWarn();
void presOK();

/********************************************* VARIABEL I:E DAN RR (Riyan) ****************************/
unsigned long waktuMillis = 0; //Waktu milisecond
unsigned long waktuInspirasi = 0; //Waktu ketika Inspirasi
unsigned long waktuEkspirasi = 0; //Waktu ketika Expirasi (relase motor servo)
unsigned long waktuEkspirasi2 = 0; //Waktu ketika Expirasi (relase setelah Limit switch tersentuh)
float pen_i = 0; // variabel penampung inspirasi
float pen_e = 0; // variabel penampung Ekspirasi
float pen_cycle = 0; //variabel penampung Cycle
int pen_rr = 0; // variabel penampung RR
int pen_ratio = 0; // Variabel penampung ratio 
/********************************************* VARIABEL I:E DAN RR (Riyan) ****************************/


/* SETUP ***************************************
- Set Serial BAUD Rate
- Update Parameter dengan parameter awal
- Set mode pin-pin & interrupt
- Lakukan kalibrasi (maju 1000 step kemudian mundur 8 detik)
************************************************/
void setup() {
  Serial.begin(115200);

  // updateParam(0, 10, 1);

  pinMode(ENA, OUTPUT);
  pinMode(PUL, OUTPUT);
  pinMode(DIR, OUTPUT);
  pinMode(ARST, OUTPUT);
  digitalWrite(ARST, HIGH);
  Serial.println("ON");
  delay(10);
  Serial.println("OFF");
  digitalWrite(ARST, LOW);

  pinMode(Bt1, INPUT_PULLUP);
  pinMode(Bt2, INPUT_PULLUP);

  pinMode(CWL, INPUT_PULLUP);
  pinMode(CCWL, INPUT_PULLUP);

  pinMode(EMGS, INPUT_PULLUP);
  pinMode(WARNN, INPUT_PULLUP);

  attachInterrupt(digitalPinToInterrupt(EMGS), updateEMGS, CHANGE);
  attachInterrupt(digitalPinToInterrupt(WARNN), triggerWarn, FALLING);

  // KALIBRASI ---
  Serial.println("Callibrating...");
  digitalWrite(ENA, HIGH);

  // Maju 1000 Step
  digitalWrite(DIR, dirInhale);
  delayMicroseconds(5);
  for(int i = 0; i < 1000; i++) {
    digitalWrite(PUL, HIGH);
    delayMicroseconds(1500);
    digitalWrite(PUL, LOW);
    delayMicroseconds(1500);
    if(digitalRead(CWL) == HIGH) break;
  }

  // Mundur 8 detik
  digitalWrite(DIR, !dirInhale);
  delayMicroseconds(5);

  unsigned long now = millis();
  while(digitalRead(CCWL) == LOW) {
    //if (millis() - now > 8000) {break;} // 2 detik maks kalibrasi
    digitalWrite(PUL, HIGH);
    delayMicroseconds(500);
    digitalWrite(PUL, LOW);
    delayMicroseconds(500);
  }

  digitalWrite(ENA, LOW);
  Serial.println("DONE, READY!"); 
  presok = 0;
}

/* LOOP ***************************************
- Listen for Serial Comm Input
- Update Global Variables
- Do Inhale and Exhale if Mode on & EMGS off
- If Mode off:
  -- Check for Button input
  -- Check for Limit Switches
***********************************************/
void loop() {
  // 1. Get Command from Serial
  updateAllGlobal();


//=========================================================================== Mandatory Volume ====================================================================  
  // 2a. If Mode Mandatory Volume Control
  if(p_mode==1){ //if(p_mode!=0 && !digitalRead(EMGS)){
    // 2a.1. Enable the Actuator
    digitalWrite(ENA, HIGH);

    if (stepTidal > 0) {
        unsigned long now = micros();

        // 2a.2. Do Inhale
        stepstop = Inhale2();
        // Added Delay for Plateau Pressure
        delayMicroseconds(100);
        // ************************************* Inhale Proses (Riyan)********************************************
            pen_i = waktuInspirasi; // Menampung waktu inspirasi ke dalam variabel pen_i
            Serial.println('{' + String("{ei}") + ',' + String(pen_rr) + ',' +  String(pen_ratio) + '}'); // Menampilkan data ketika Inhale selesai
            waktuEkspirasi = 0 ; // Mereset Expirasi (dari motor)
            waktuEkspirasi2 = 0 ; // Mereset Expirasi (setelah Limitswitch Luar tertekan)
        // ************************************* Inhale Proses (Riyan)********************************************
        Serial.flush();

        // 2a.3. Do Exhale
        Exhale(stepstop);
        // Idling
        while((micros()-now) < timeBreath){
        //***********************************Hitung waktu Ekspirasi setelah limitswitch exhale tertekan (Riyan)********************************************
            if (millis()-waktuMillis>=1){
            waktuEkspirasi2  = waktuEkspirasi2 + 1;
            waktuMillis = millis();
              }
        //***********************************Hitung waktu Ekspirasi setelah limitswitch exhale tertekan (Riyan)********************************************
          }
        // *************************************Perhitungan RR, I:E, dan Exhale Proses (Riyan)*************************************
              pen_e = waktuEkspirasi + waktuEkspirasi2; // Penggabungan waktu Expirasi motor dan expirasi setelah limitswitch tertekan
              pen_cycle = (pen_i) + (pen_e); //penggabungan waktu Inpirasi dan Ekspirasi
              pen_rr = round(60000/pen_cycle); //perhitungan waktu Respiration Rate (RR)
              pen_ratio = round(pen_e / pen_i); //Perhitungan I:E 
              Serial.println('{' + String("{ec}") + ',' + String(pen_rr) + ',' +  String(pen_ratio) + '}'); // Menampilkan data ketika Exhale selesai
              waktuInspirasi = 0 ; // Mereset waktu Inspirasi
        // *************************************Perhitungan RR, I:E, dan Exhale Proses (Riyan)*************************************     
        Serial.flush();

    } else {
      //throw error message
    }
  }
//===========================================================================Mandatory Pressure====================================================================  
  if(p_mode==2){ //Mode Mandatory Pressure
    // 2b.1. Enable the Actuator
    digitalWrite(ENA, HIGH);

    if (stepTidal > 0) {
        unsigned long now = micros();

        // 2b.2. Do Inhale
        stepstop = Inhale3();
        // Added Delay for Plateau Pressure
        delayMicroseconds(100);

        // ************************************* Inhale Proses (Riyan)********************************************
            pen_i = waktuInspirasi; // Menampung waktu inspirasi ke dalam variabel pen_i
            Serial.println('{' + String("{ei}") + ',' + String(pen_rr) + ',' +  String(pen_ratio) + '}'); // Menampilkan data ketika Inhale selesai
            waktuEkspirasi = 0 ; // Mereset Expirasi (dari motor)
            waktuEkspirasi2 = 0 ; // Mereset Expirasi (setelah Limitswitch Luar tertekan)
        // ************************************* Inhale Proses (Riyan)********************************************
        Serial.flush();

        // 2b.3. Do Exhale
        Exhale3(stepstop); // Exhale3(stepstop);
        // Idling
        while((micros()-now) < timeBreath){
        //***********************************Hitung waktu Ekspirasi setelah limitswitch exhale tertekan (Riyan)********************************************
            if (millis()-waktuMillis>=1){
            waktuEkspirasi2  = waktuEkspirasi2 + 1;
            waktuMillis = millis();
              }
        //***********************************Hitung waktu Ekspirasi setelah limitswitch exhale tertekan (Riyan)********************************************
          }
        // *************************************Perhitungan RR, I:E, dan Exhale Proses (Riyan)*************************************
              pen_e = waktuEkspirasi + waktuEkspirasi2; // Penggabungan waktu Expirasi motor dan expirasi setelah limitswitch tertekan
              pen_cycle = (pen_i) + (pen_e); //penggabungan waktu Inpirasi dan Ekspirasi
              pen_rr = round(60000/pen_cycle); //perhitungan waktu Respiration Rate (RR)
              pen_ratio = round(pen_e / pen_i); //Perhitungan I:E 
              Serial.println('{' + String("{ec}") + ',' + String(pen_rr) + ',' +  String(pen_ratio) + '}'); // Menampilkan data ketika Exhale selesai
              waktuInspirasi = 0 ; // Mereset waktu Inspirasi
        // *************************************Perhitungan RR, I:E, dan Exhale Proses (Riyan)*************************************     
        Serial.flush();
    }
    
  }

//==============================================================================Off Mode=========================================================================  
  // 2c. If Mode OFF
  if(p_mode==0) {
    // 2c.1. Disable the Actuator
    digitalWrite(ENA, LOW);

    // 2c.2. Check For Limit Switches
    if(digitalRead(CCWL) == HIGH){
      Serial.println("CCWL");
    }
    if(digitalRead(CWL) == HIGH){
      Serial.println("CWL");
    }

    // 2c.3. Check For Emergency Button
    if(digitalRead(EMGS)){
      Serial.println("{ee}");
    } else {
      Serial.println("Waiting.. (mode 0 )");
    }

    Serial.flush();
    delay(1000);

    // 2c.4. Check for Manual Input
    if(digitalRead(Bt1) == LOW){
      digitalWrite(ENA, HIGH);
      digitalWrite(DIR, dirInhale);
      Serial.println("MAJU!");
      while(digitalRead(Bt1) == LOW){
        digitalWrite(PUL, HIGH);
        delayMicroseconds(delayq);
        digitalWrite(PUL, LOW);
        delayMicroseconds(delayq);
      }
    } else if(digitalRead(Bt2) == LOW){
      digitalWrite(ENA, HIGH);
      digitalWrite(DIR, !dirInhale);
      Serial.println("MUNDUR!");
      while(digitalRead(Bt2) == LOW){
        digitalWrite(PUL, HIGH);
        delayMicroseconds(delayq);
        digitalWrite(PUL, LOW);
        delayMicroseconds(delayq);
      }
    }
  }
}

/**************************
*      COMM FUNCTIONS     *
***************************/

/* Update Global Variables **********************
*  Update most global values dari data Serial
*  return: None
*************************************************/
void updateAllGlobal(){
  String received = readSerial();
  if(!updated) {
    Serial.print("Received: ");
    Serial.println(received);
    Serial.flush();

    int indexStart = 0;
    int indexEnd = 0;

    for(int i = 0; i<num_buf; i++) {
      indexEnd = received.indexOf(",", indexStart);
      bufferq[i] = received.substring(indexStart, indexEnd);
      indexStart = indexEnd+1;
    }

    p_mode = bufferq[0].toInt(); // Mode
    p_vol = bufferq[1].toInt(); // Stepper motor set
    p_RR = bufferq[2].toInt(); // RR Set
    p_IE = bufferq[3].toFloat(); // IE Set
    p_del = bufferq[4].toFloat(); // koreksi waktu
    p_pres = bufferq[5].toInt(); // Pressure set
    p_press = bufferq[6].toFloat(); // pressure sensor

    updateParam(p_vol, p_RR, p_IE);

    updated = true;
  }
}

/* Read Serial **************************
*  Fungsi untuk membaca string yang masuk ke Serial
*  return: String
********************************************/
String readSerial(){
  bool quit = false;
  String seriesData = "";

  while (!quit) {
    if (Serial.available() > 0) {
      updated = false;
      seriesData = Serial.readString();
      quit = true;
    } else {
      seriesData = lastData;
      quit = true;
    }
  }

  lastData = seriesData;

  return seriesData.substring(1,seriesData.length()-1);
}

/* Update Param **********************
*  Update parameter gerakan berdasar variable global baru
*  return: None
*************************************************/
void updateParam(float vol, int RRq, float ERatq){
  stepTidal = vol;
  timeBreath = (60000 / float(RRq)) * 1000;
  timeInhale = (60000 / float(RRq)) * (float(IRat) / float(IRat + ERatq)) * 1000 - 500; // dalam microseconds

  float offsetInhaleq= 0;
  float a,b,c;

  timeInhale += p_del/2*1000000;

  timeExhale = (60000 / float(RRq)) * (float(ERatq) / float(IRat + ERatq)) * 1000; // dalam microseconds
  delayInhale = float(timeInhale) / float(stepTidal) / 2; //endDelay; // dalam microseconds
  delayExhale = 20; //delayInhale; // dalam microseconds

  Serial.println("----");
  Serial.println("RR = " + String(RRq));
  Serial.println("IE = " + String(ERatq));
  Serial.println("Vol Tidal = " + String(vol));
  Serial.println("Step Tidal = " + String(stepTidal));
  Serial.println("Slope Tidal = " + String(slopeFactor));
  Serial.println("----");
  Serial.println("DELAY Awal = " + String(initDelay));
  Serial.println("DELAY Inhale = " + String(delayInhale));
  Serial.println("DELAY Exhale = " + String(delayExhale));
  Serial.println("----");
  Serial.println("WAKTU BREATH = " + String(timeBreath));
  Serial.println("WAKTU IDEAL Inhale = " + String(timeInhale));
  Serial.println("WAKTU IDEAL Exhale = " + String(timeExhale));
  Serial.println("----");

  Serial.println("updateParam()");
  Serial.flush();
}


/**************************
*   MOVEMENT FUNCTIONS    *
***************************/

/* Inhale Volume Sequence ****************************/
int Inhale2() { //assisted inhale
  // 0. Hitung Waktu
  int stepstop = stepTidal;
  float delayInhale2 = delayInhale-offsetq;

  // 1. Set Arah
  digitalWrite(DIR, dirInhale);
  delayMicroseconds(5);

  // 2. Set Gerakan Stepper
  for(int i = 0; i < stepTidal; i++) {
    digitalWrite(PUL, HIGH);
    delayMicroseconds(delayInhale2);
    digitalWrite(PUL, LOW);
    delayMicroseconds(delayInhale2);

    //***********************************Hitung waktu Inspirasi (Riyan)********************************************
      if (millis()-waktuMillis>=1){
      waktuInspirasi = waktuInspirasi + 1;
      waktuMillis =millis();
      }
    //***********************************Hitung waktu Inspirasi (Riyan)********************************************

    
    if(warnq == true) {
      stepstop = i;
      break;
    }
  }
  warnq = false;

  // Return jumlah step yang telah dilakukan
  return stepstop;
}


/* Exhale Volume Sequence **********************/
void Exhale(int stepTidalq) {
  // 0. Hitung Waktu
  unsigned long now = micros();
  float delayExhale2 = initDelay;

  // 1. Set Arah
  digitalWrite(DIR, !dirInhale);
  delayMicroseconds(5);

  // 2. Set Gerakan Stepper
  for(int i = 0; i < stepTidalq; i++) {


      //***********************************Hitung waktu Ekspirasi (Riyan)********************************************
        if (millis()-waktuMillis>=1){
        waktuEkspirasi  = waktuEkspirasi + 1;
        waktuMillis = millis();
        }
      //***********************************Hitung waktu Ekspirasi (Riyan)********************************************


    
    if(i < slopeFactor*stepTidalq){
      delayExhale2 -= (initDelay-delayExhale) / (slopeFactor*stepTidalq);
    }
    if(i>(1-slopeFactor)*stepTidalq){
      delayExhale2 += (initDelay-delayExhale) / (slopeFactor*stepTidalq);
    }

    digitalWrite(PUL, HIGH);
    delayMicroseconds(delayExhale2);
    digitalWrite(PUL, LOW);
    delayMicroseconds(delayExhale2);   

    if(digitalRead(CCWL) == HIGH){
      Serial.println("CCWL");
      break;
    }
  }
}



/* Inhale Pressure Sequence ****************************/
int Inhale3() { //assisted inhale
  // 0. Hitung Waktu
  int stepstop = stepTidal;
  float delayInhale2 = delayInhale-offsetq;
  unsigned long now2 = millis();
  
  // 1. Set Arah
  digitalWrite(DIR, dirInhale);
  delayMicroseconds(5);

 
  // 3. Set Gerakan Stepper
  for(int i = 0; i < 10000; i++) {

    if(presok == 0){
    digitalWrite(PUL, HIGH);
    delayMicroseconds(delayInhale2);
    digitalWrite(PUL, LOW);
    delayMicroseconds(delayInhale2);
    }
    
    //***********************************Hitung waktu Inspirasi (Riyan)********************************************
      if (millis()-waktuMillis>=1){
      waktuInspirasi = waktuInspirasi + 1;
      waktuMillis =millis();
      }
    //***********************************Hitung waktu Inspirasi (Riyan)********************************************


    //4. Interrupt Raspi saat Sensor Pressure lebih besar dari set Poin  
        if(presok == 1){ 
            Serial.println('{' + String("{ei3}") + ',' + String(pen_rr) + ',' +  String(pen_ratio) +  '}'); // Menampilkan data ketika Inhale selesai
        for(int x=0;x<5000; x++){
        int f = (millis() - now2); 
        int g = timeInhale/1000;
        digitalWrite(PUL, LOW); // LOW 
        delayMicroseconds(delayInhale2);  

                if (f >= g){ //Saat waktu Inspirasi sudah habis
                  digitalWrite(PUL, LOW);
                  delayMicroseconds(delayInhale2);
                  f = millis();
                  presok3 = 1;
                  break;
                  }
                }
              }

        if(presok3 == 1){
          stepstop = i;
          break;
          }                 
      }
    presok3=0;
    presok=0;
    return stepstop;
  }    

  


/* Exhale Presure Sequence **********************/
void Exhale3(int stepTidalq) {
  // 0. Hitung Waktu
  unsigned long now = micros();
  float delayExhale2 = initDelay;

  // 1. Set Arah
  digitalWrite(DIR, !dirInhale);
  delayMicroseconds(5);

  // 2. Set Gerakan Stepper
  for(int i = 0; i < stepTidalq; i++) {
             
      //***********************************Hitung waktu Ekspirasi (Riyan)********************************************
        if (millis()-waktuMillis>=1){
        waktuEkspirasi  = waktuEkspirasi + 1;
        waktuMillis = millis();
        }
      //***********************************Hitung waktu Ekspirasi (Riyan)********************************************

    
    if(i < slopeFactor*stepTidalq){
      delayExhale2 -= (initDelay-delayExhale) / (slopeFactor*stepTidalq);
    }
    if(i>(1-slopeFactor)*stepTidalq){
      delayExhale2 += (initDelay-delayExhale) / (slopeFactor*stepTidalq);
    }
//    Serial.println("exhale");
    digitalWrite(PUL, HIGH);
    delayMicroseconds(delayExhale2);
    digitalWrite(PUL, LOW);
    delayMicroseconds(delayExhale2);   

    if(digitalRead(CCWL) == HIGH){
      Serial.println("CCWL");
      break;
    }
  }
}




/**************************
*   INTERRUPT FUNCTIONS   *
***************************/

/* Update Status Warning ***************************/
void triggerWarn(){
  presok = 1;
}


/* Update Status EMGS ***************************/
void updateEMGS(){
  if(digitalRead(EMGS) == HIGH) {
    //kirim perintah ke raspi
    Serial.println("{ee}");
  } else { //EMGS OFF
    Serial.println("EE off");
  }
}

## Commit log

2021-05-27 Added Dokumentasi Kalibrasi dan Pra Klinis
    [format_kalibrasi.xlsx]
2021-06-04 Added latest schematics
    [venti_ver2.0.brd, venti_ver2.0.sch]
2021-06-07 Update dokumen planning
    [Timeline dan Action Plan Ventilator Lanjutan (Draft).xlsx, format_kalibrasi.xlsx]
2021-09-30 Mandatory Pressure Control
    [Book3.csv]

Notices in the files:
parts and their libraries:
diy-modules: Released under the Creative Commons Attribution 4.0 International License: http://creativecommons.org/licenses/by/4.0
